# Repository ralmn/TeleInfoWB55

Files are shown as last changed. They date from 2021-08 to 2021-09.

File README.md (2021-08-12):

# TeleInfo - ST32WB55

[Version Française / French version](README.FR.md)

This project allows to get the information from the French Linky electric meters (and old meters) via the customer tele-information terminals "TIC" and transmit them in Zigbee. The module is powered by the 150mW dedicated power supply of the Linky.

This repository contains the Kicad sources of the PCB and the sources of the Firmware.

## PCB

The PCB is based on :
* A microcontroller [STM32WB55CCU6](https://www.st.com/en/microcontrollers-microprocessors/stm32wb55cc.html) which takes care of the information retrieval and retransmission in Zigbee
* A diode bridge for the conversion of the AC power supply of the linky into DC.
* A linear regulator LM2937-IMP for the conversion in 3.3V
* One SHA620-A octocoupler for serial link recovery from the TeleInfo
* 2 x 5V power supply pins (5V and GND) for the old counters. With a jumper for the choice between Linky/5V
* 5 pins to flash the microcontroller with a st-link (SWD).

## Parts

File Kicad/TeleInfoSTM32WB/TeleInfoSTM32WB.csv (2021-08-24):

Comment | Designator | Footprint | LCSC
100nF | C1,C7,C9,C12,C13,C14,C15,C16,C18,C20 | Capacitor_SMD:C_0805_2012Metric_Pad1.18x1.45mm_HandSolder | C138340
0.3pF | C11 | Capacitor_SMD:C_0805_2012Metric_Pad1.18x1.45mm_HandSolder | C138340
4.7uF | C17,C19 | Capacitor_SMD:C_0805_2012Metric_Pad1.18x1.45mm_HandSolder | C464454
15pF | C2,C3 | Capacitor_SMD:C_0805_2012Metric_Pad1.18x1.45mm_HandSolder | C705013
100pF | C4 | Capacitor_SMD:C_0805_2012Metric_Pad1.18x1.45mm_HandSolder | C464454
0.8pF | C5 | Capacitor_SMD:C_0805_2012Metric_Pad1.18x1.45mm_HandSolder | C464454
10uF | C6,C10 | Capacitor_SMD:C_0805_2012Metric_Pad1.18x1.45mm_HandSolder | C89827
LED | D2,D3 | LED_SMD:LED_0805_2012Metric_Pad1.15x1.40mm_HandSolder | C389523
BAT54S | D5,D6 | Package_TO_SOT_SMD:SOT-23 | C258194
2450LP14B100T | FL1 | Customs:2450LP14B100T
Conn_01x02_Female | J1 | Connector_PinHeader_2.54mm:PinHeader_1x02_P2.54mm_Vertical | C160332
Conn_01x05_Female | J2,J4 | Connector_PinHeader_2.54mm:PinHeader_1x05_P2.54mm_Vertical | C358687
RSP-122811-01 | J3 | RSP-122811-01:SAMTEC_RSP-122811-01 | C434808
Jumper_3_Open | JP1 | Jumper:SolderJumper-3_P1.3mm_Open_Pad1.0x1.5mm
SolderJumper_3_Open | JP2 | Jumper:SolderJumper-3_P1.3mm_Open_Pad1.0x1.5mm
2.7nH | L1 | Inductor_SMD:L_0603_1608Metric_Pad1.05x0.95mm_HandSolder
Z0603C601ASMST | L2 | Inductor_SMD:L_0603_1608Metric_Pad1.05x0.95mm_HandSolder
10nH | L3 | Inductor_SMD:L_0805_2012Metric
10nH | L4 | Inductor_SMD:L_0603_1608Metric_Pad1.05x0.95mm_HandSolder
R750 | R2,R3 | Resistor_SMD:R_0805_2012Metric_Pad1.20x1.40mm_HandSolder | C351549
3.3K | R6 | Resistor_SMD:R_0805_2012Metric_Pad1.20x1.40mm_HandSolder | C352211
SW_Push | SW1 | Button_Switch_SMD:SwitchSPST | C127404
STM32WB55CCUx | U1 | STM32:STM32WB55CCU6 | C2151725
SFH620A-1 | U2 | Package_DIP:DIP-4_W7.62mm | C500642
LM2937-IMP | U3 | Package_TO_SOT_SMD:SOT-223-3_TabPin2 | C140265
32.768 KHz | Y1 | Crystal:Crystal_SMD_TXC_9HT11-2Pin_2.0x1.2mm_HandSoldering | C409344
Crystal_GND24 | Y2 | Crystal:Crystal_SMD_TXC_7M-4Pin_3.2x2.5mm_HandSoldering | C91742

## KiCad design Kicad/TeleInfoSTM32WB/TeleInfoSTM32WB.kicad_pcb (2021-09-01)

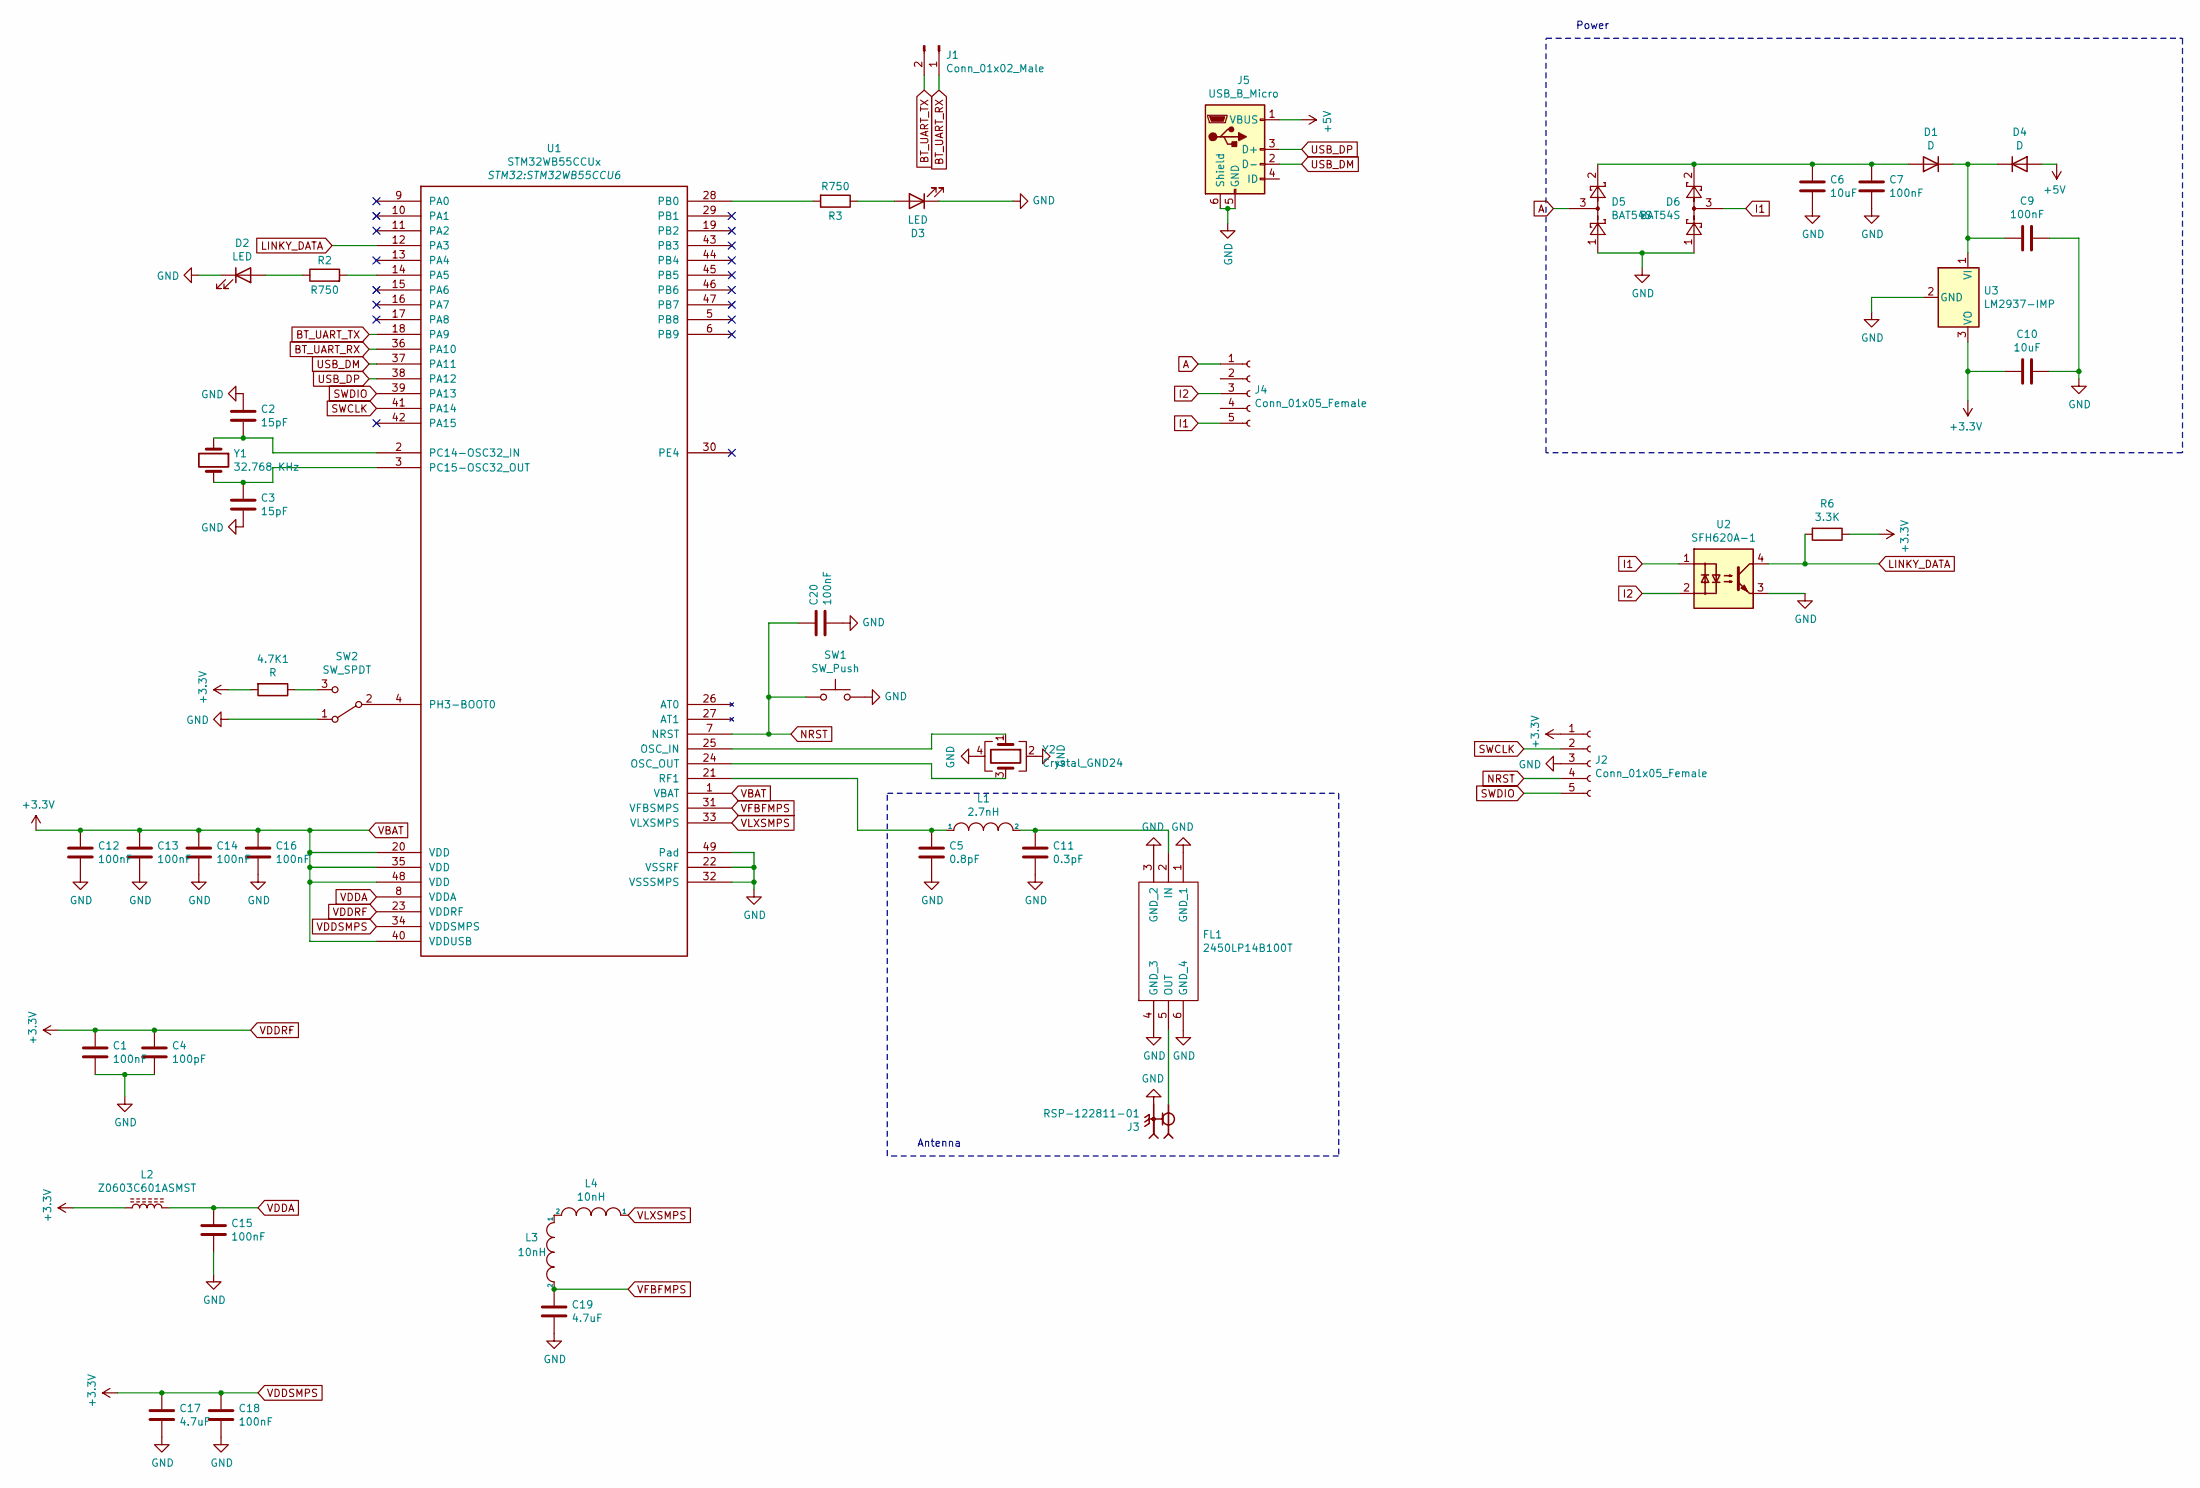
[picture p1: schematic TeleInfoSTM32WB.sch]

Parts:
4.7K1: R; R_0805_2012Metric
C1, C7, C9, C12, C13, C14, C15, C16, C20: 100nF; C_0805_2012Metric_Pad1.18x1.45mm_HandSolder; LCSC C138340
C2, C3: 15pF; C_0805_2012Metric_Pad1.18x1.45mm_HandSolder; LCSC C705013
C4: 100pF; C_0805_2012Metric_Pad1.18x1.45mm_HandSolder; LCSC C464454
C5: 0.8pF; C_0805_2012Metric_Pad1.18x1.45mm_HandSolder; LCSC C464454
C6, C10: 10uF; C_0805_2012Metric_Pad1.18x1.45mm_HandSolder; LCSC C89827
C11: 0.3pF; C_0805_2012Metric_Pad1.18x1.45mm_HandSolder; LCSC C138340
C17, C19: 4.7uF; C_0805_2012Metric_Pad1.18x1.45mm_HandSolder; LCSC C464454
C18: 100nF; C_0805_2012Metric_Pad1.18x1.45mm_HandSolder; LCSC C464454
D1, D4: D; D_SOD-123F
D2, D3: LED; LED_0805_2012Metric_Pad1.15x1.40mm_HandSolder; LCSC C389523
D5, D6: BAT54S; SOT-23; LCSC C258194
FL1: 2450LP14B100T; Manufacturer_Part_Number 2450LP14B100T; Mouser Part Number 609-2450LP14B100T
J1: Conn_01x02_Male; PinHeader_1x02_P2.54mm_Vertical
J2: Conn_01x05_Female; PinHeader_1x05_P2.54mm_Vertical; LCSC C358687
J3: RSP-122811-01; SAMTEC_RSP-122811-01; PARTREV H; LCSC C434808
J4: Conn_01x05_Female; PinHeader_1x05_P2.54mm_Vertical; LCSC C180219
J5: USB_B_Micro; USB_Micro-B_Molex_47346-0001
L1: 2.7nH; L_0603_1608Metric_Pad1.05x0.95mm_HandSolder
L2: Z0603C601ASMST; L_0603_1608Metric_Pad1.05x0.95mm_HandSolder
L3, L4: 10nH; L_0805_2012Metric
R2, R3: R750; R_0805_2012Metric_Pad1.20x1.40mm_HandSolder; LCSC C351549
R6: 3.3K; R_0805_2012Metric_Pad1.20x1.40mm_HandSolder; LCSC C352211
SW1: SW_Push; SwitchSPST; LCSC C127404
SW2: SW_SPDT; SW_SPDT_CK-JS102011SAQN
U1: STM32WB55CCUx; STM32WB55CCU6; LCSC C2151725
U2: SFH620A-1; DIP-4_W7.62mm; LCSC C500642
U3: LM2937-IMP; SOT-223-3_TabPin2; LCSC C140265
Y1: 32.768 KHz; Crystal_SMD_TXC_9HT11-2Pin_2.0x1.2mm_HandSoldering; LCSC C409344
Y2: Crystal_GND24; Crystal_SMD_TXC_7M-4Pin_3.2x2.5mm_HandSoldering; LCSC C91742

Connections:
+5V: D4.2 (A), J5.1 (VBUS)
A: D5.3, J4.1
BT_UART_RX: J1.1, U1.36 (PA10)
BT_UART_TX: J1.2, U1.18 (PA9)
GND: C1.2, C2.1, C3.2, C4.2, C5.2, C6.2, C7.2, C9.1, C10.1, C11.2, C12.2, C13.2, C14.2, C15.2, C16.2, C17.2, C18.2, C19.2, C20.2, D2.1 (K), D3.1 (K), D5.1, D6.1, FL1.1 (GND_1), FL1.3 (GND_2), FL1.4 (GND_3), FL1.6 (GND_4), J2.3, J3.G1, J3.G2, J5.5 (GND), J5.6 (Shield), SW1.2, SW2.1 (A), U1.22 (VSSRF), U1.32 (VSSSMPS), U1.49 (Pad), U2.3, U3.2 (GND), Y2.2, Y2.4
I1: D6.3, J4.5, U2.1
I2: J4.3, U2.2
LINKY_DATA: R6.2, U1.12 (PA3), U2.4
NRST: C20.1, J2.4, SW1.1, U1.7 (NRST)
unnamed: 4.7K1.1, SW2.3 (C)
unnamed: C2.2, U1.2 (PC14-OSC32_IN), Y1.1
unnamed: C3.1, U1.3 (PC15-OSC32_OUT), Y1.2
unnamed: C5.1, L1.1, U1.21 (RF1)
unnamed: C6.1, C7.1, D1.2 (A), D5.2, D6.2
unnamed: C9.2, D1.1 (K), D4.1 (K), U3.1 (VI)
unnamed: C11.1, FL1.2 (IN), L1.2
unnamed: D2.2 (A), R2.1
unnamed: D3.2 (A), R3.1
unnamed: FL1.5 (OUT), J3.1
unnamed: L3.1, L4.2
unnamed: R2.2, U1.14 (PA5)
unnamed: R3.2, U1.28 (PB0)
unnamed: SW2.2 (B), U1.4 (PH3-BOOT0)
unnamed: U1.24 (OSC_OUT), Y2.3
unnamed: U1.25 (OSC_IN), Y2.1
SWCLK: J2.2, U1.41 (PA14)
SWDIO: J2.5, U1.39 (PA13)
USB_DM: J5.2 (D-), U1.37 (PA11)
USB_DP: J5.3 (D+), U1.38 (PA12)
VBAT: 4.7K1.2, C1.1, C4.1, C10.2, C12.1, C13.1, C14.1, C16.1, C17.1, C18.1, J2.1, L2.1, R6.1, U1.1 (VBAT), U1.20 (VDD), U1.23 (VDDRF), U1.34 (VDDSMPS), U1.35 (VDD), U1.40 (VDDUSB), U1.48 (VDD), U3.3 (VO)
VDDA: C15.1, L2.2, U1.8 (VDDA)
VFBFMPS: C19.1, L3.2, U1.31 (VFBSMPS)
VLXSMPS: L4.1, U1.33 (VLXSMPS)

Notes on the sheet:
Power
Antenna

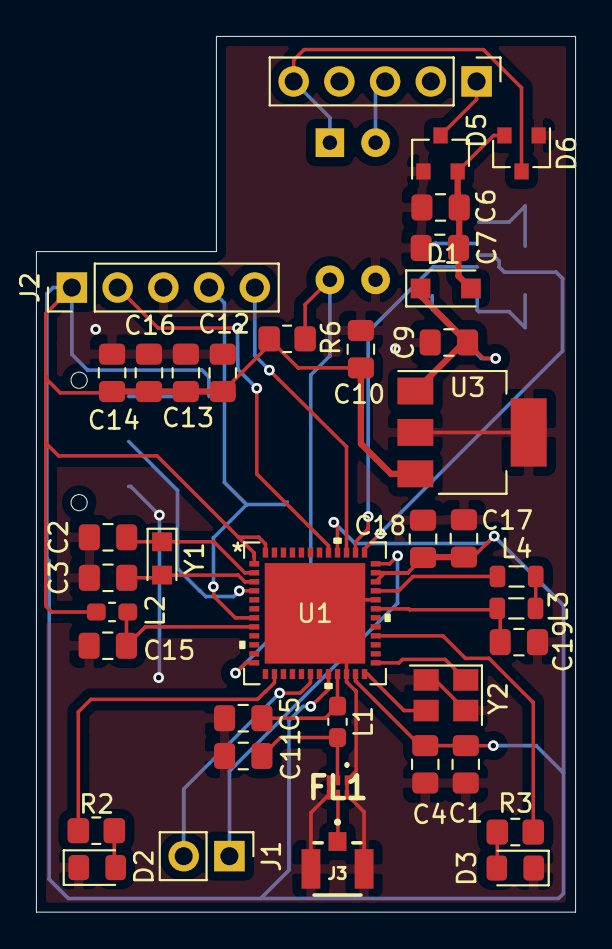
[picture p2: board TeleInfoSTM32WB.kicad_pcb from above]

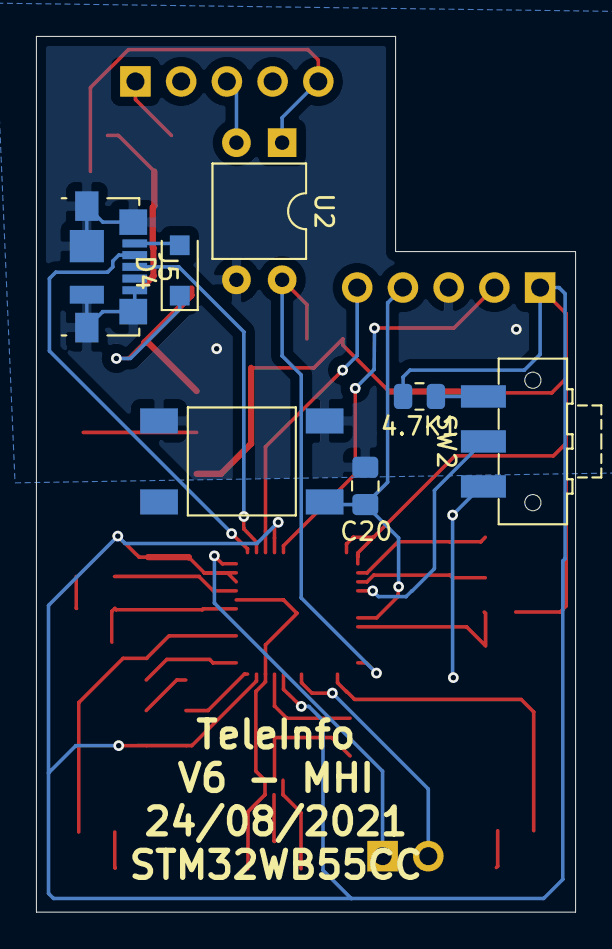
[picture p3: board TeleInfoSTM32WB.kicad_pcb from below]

Board: 2 copper layers, 30.0 x 48.6 mm, 46 parts (7 on the bottom side), 33 nets.

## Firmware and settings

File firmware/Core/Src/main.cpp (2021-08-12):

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
/* Includes ------------------------------------------------------------------*/
#include "main.h"

/* USER CODE BEGIN Includes */
#include "LibTeleinfo.hpp"
#include "app_zigbee.h"
/* USER CODE END Includes */

IPCC_HandleTypeDef hipcc;

UART_HandleTypeDef hlpuart1;

RTC_HandleTypeDef hrtc;

void SystemClock_Config(void);
static void MX_GPIO_Init(void);
static void MX_IPCC_Init(void);
static void MX_LPUART1_UART_Init(void);
static void MX_RF_Init(void);
static void MX_RTC_Init(void);
/* USER CODE BEGIN PFP */
void TeleInfo_Data(ValueList *valueslist, uint8_t state);
/* USER CODE END PFP */

/* USER CODE BEGIN 0 */
TInfo _tinfo;
char dataUART;
/* USER CODE END 0 */

/**
  * @brief  The application entry point.
  * @retval int
  */
int main(void)
{
  /* MCU Configuration--------------------------------------------------------*/

  /* Reset of all peripherals, Initializes the Flash interface and the Systick. */
  HAL_Init();
  /* Config code for STM32_WPAN (HSE Tuning must be done before system clock configuration) */
  MX_APPE_Config();

  /* Configure the system clock */
  SystemClock_Config();

  /* IPCC initialisation */
   MX_IPCC_Init();

  /* Initialize all configured peripherals */
  MX_GPIO_Init();
  MX_LPUART1_UART_Init();
  MX_RF_Init();
  MX_RTC_Init();
  /* Init code for STM32_WPAN */
  MX_APPE_Init();
  /* Infinite loop */
  /* USER CODE BEGIN WHILE */
  uint32_t last, now;

  _tinfo.init();
  _tinfo.attachData(&TeleInfo_Data);
  last = HAL_GetTick();
  while (1)
  {
    /* USER CODE END WHILE */
    MX_APPE_Process();

    /* USER CODE BEGIN 3 */
  }
  /* USER CODE END 3 */
}

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
/* USER CODE BEGIN 4 */
void TeleInfo_Data(ValueList *valueslist, uint8_t state) {

	if (strcmp(valueslist->name, "PAPP") == 0) {
		int zz = atoi(valueslist->value);
		uint16_t  val = (uint16_t) zz ;
		APP_ZIGBEE_TeleInfo_ApparentPower(val);
	} else if (strcmp(valueslist->name, "IMAX") == 0) {
		int zz = atoi(valueslist->value);
		uint16_t  val = (uint16_t) zz ;
		APP_ZIGBEE_TeleInfo_CurrentMax(val);
	}else  if (strcmp(valueslist->name, "IINST") == 0) {
		int zz = atoi(valueslist->value);
		uint16_t  val = (uint16_t) zz ;
		APP_ZIGBEE_TeleInfo_Current(val);
	}else  if (strcmp(valueslist->name, "BASE") == 0) {
		long zz = atol(valueslist->value);
		uint32_t  val = (uint32_t) zz;
		APP_ZIGBEE_TeleInfo_TotalActivePower(val);
	}

}

#ifdef __cplusplus
extern "C" {
#endif
void HAL_UART_RxCpltCallback(UART_HandleTypeDef *huart)
{
  if (huart->Instance == LPUART1)
  {
    _tinfo.process(dataUART);
    HAL_UART_Receive_IT(&hlpuart1, (uint8_t*) &dataUART, 1);
  }
}
#ifdef __cplusplus
}
#endif

/* USER CODE END 4 */
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


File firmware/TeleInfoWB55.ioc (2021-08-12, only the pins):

Mcu.UserName=STM32WB55CCUx
PA13.Signal=SYS_JTMS-SWDIO
PA14.Signal=SYS_JTCK-SWCLK
PA2.Signal=LPUART1_TX
PA3.Signal=LPUART1_RX
PC14-OSC32_IN.Signal=RCC_OSC32_IN
PC15-OSC32_OUT.Signal=RCC_OSC32_OUT

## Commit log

2021-08-12 Inital commit
    [TeleInfoSTM32WB.kicad_pcb, TeleInfoSTM32WB.sch]
2021-08-24 PCB v6
    [TeleInfoSTM32WB.csv, TeleInfoSTM32WB.dsn]
2021-09-01 PCB V6 (forget commited filed.... :clap:)
    [TeleInfoSTM32WB.kicad_pcb, TeleInfoSTM32WB.sch]
2021-09-01 Update symbols and footprint libs path + add gitignore + remove useless files
    [TeleInfoSTM32WB.dsn]
2021-09-01 Update symbol stm32wb55
    [TeleInfoSTM32WB.sch]

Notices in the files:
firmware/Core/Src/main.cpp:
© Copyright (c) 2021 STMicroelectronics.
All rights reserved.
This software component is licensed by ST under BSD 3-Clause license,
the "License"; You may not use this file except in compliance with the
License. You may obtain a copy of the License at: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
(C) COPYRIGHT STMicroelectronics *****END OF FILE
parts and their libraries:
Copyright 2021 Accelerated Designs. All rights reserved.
